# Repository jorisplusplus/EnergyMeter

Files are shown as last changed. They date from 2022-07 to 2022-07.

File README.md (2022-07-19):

PCB and esphome configuration for reading P1 smart meter and RS485 Modbus devices (pv systems)

## Hardware ##
Hardware production files are found in the production folder. These files can be generated with the generate.sh command (requires kikit to be installed).

## ESPHOME ##
In the esphome folder there are 2 configuration files for P1 Meter and Goodwe xs inverter. Note both configurations use the ethernet port

## Housing ##
In the Housing folder the openscad and stl files are present. The pcb should fit pressfit in the housing.

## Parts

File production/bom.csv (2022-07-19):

Comment | Designator | Footprint | LCSC
470uF | C1,C3 | Capacitor_THT:CP_Radial_D8.0mm_P3.50mm | C1590895
DNP | C2,C7,C8,C19,C20 | Capacitor_SMD:C_0603_1608Metric
100nF | C4,C5,C6,C9,C10,C11,C12,C13,C15,C17 | Capacitor_SMD:C_0603_1608Metric | C14663
200pF | C14 | Capacitor_SMD:C_0603_1608Metric | C1600
1uF | C16 | Capacitor_SMD:C_0603_1608Metric | C15849
10nF | C18 | Capacitor_SMD:C_0603_1608Metric | C57112
LED | D1,D2 | LED_SMD:LED_0805_2012Metric | C84256
1N5819 | D3 | Diode_SMD:D_SOD-323 | C191023
10 | FB1 | Resistor_SMD:R_0805_2012Metric | C1017
5V_SELECTOR | J1 | Connector_PinHeader_2.54mm:PinHeader_2x03_P2.54mm_Horizontal
RJ12 | J2,J4 | Connector_RJ:RJ12_Amphenol_54601 | C305981
PS | J3 | Connector_PinHeader_2.54mm:PinHeader_1x03_P2.54mm_Vertical
USB_C_Receptacle_USB2.0 | J5 | Connector_USB:USB_C_Receptacle_HRO_TYPE-C-31-M-12 | C165948
RJ45_Amphenol_RJMG1BD3B8K1ANR | J6 | Connector_RJ:RJ45_Hanrun_HR911105A | C12074
22uH | L1 | Inductor_SMD:L_Taiyo-Yuden_NR-40xx | C83472
S8050 | Q1,Q2 | Package_TO_SOT_SMD:SOT-23 | C2146
470 | R1,R2 | Resistor_SMD:R_0603_1608Metric | C23179
180 | R3 | Resistor_SMD:R_0603_1608Metric | C22828
1K | R4,R5 | Resistor_SMD:R_0603_1608Metric | C21190
DNP | R6 | Resistor_SMD:R_0603_1608Metric
5.1k | R7,R8 | Resistor_SMD:R_0603_1608Metric | C23186
10k | R9,R10 | Resistor_SMD:R_0603_1608Metric | C25804
4K7 | R11,R13,R14,R15,R16 | Resistor_SMD:R_0603_1608Metric | C23162
1K5 | R12 | Resistor_SMD:R_0603_1608Metric | C22843
330 | R17 | Resistor_SMD:R_0603_1608Metric | C23138
270 | R18 | Resistor_SMD:R_0603_1608Metric | C22966
12K1 | R19 | Resistor_SMD:R_0603_1608Metric
49.9 | R20,R21,R22,R23 | Resistor_SMD:R_0603_1608Metric | C23185
0 | R24 | Resistor_SMD:R_0603_1608Metric | C21189
680 | R25,R27 | Resistor_SMD:R_0603_1608Metric | C23228
120 | R26 | Resistor_SMD:R_0603_1608Metric | C22787
1.5K | R28 | Resistor_SMD:R_0603_1608Metric | C22843
10k | R29,R30 | Resistor_SMD:R_0603_1608Metric
ESP32-WROOM-32 | U1 | RF_Module:ESP32-WROOM-32 | C82899
XL1509 | U2 | Package_SO:SOP-8_3.9x4.9mm_P1.27mm | C74192
SN74LVC1T45DCK | U3,U4 | Package_TO_SOT_SMD:SOT-363_SC-70-6 | C133077
SP3485EN | U5 | Package_SO:SOIC-8_3.9x4.9mm_P1.27mm | C8963
CH340C | U6 | Package_SO:SOIC-16_3.9x9.9mm_P1.27mm | C84681
LAN8720A | U7 | Package_DFN_QFN:QFN-24-1EP_4x4mm_P0.5mm_EP2.6x2.6mm | C45223

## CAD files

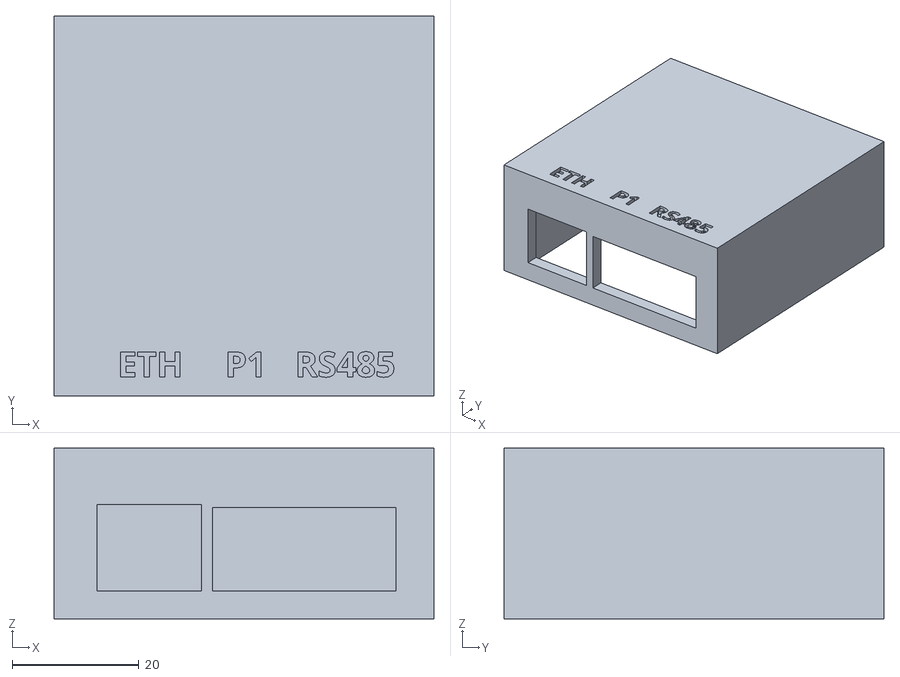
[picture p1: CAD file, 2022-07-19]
Housing/top.stl
60.0 x 60.0 x 27.0

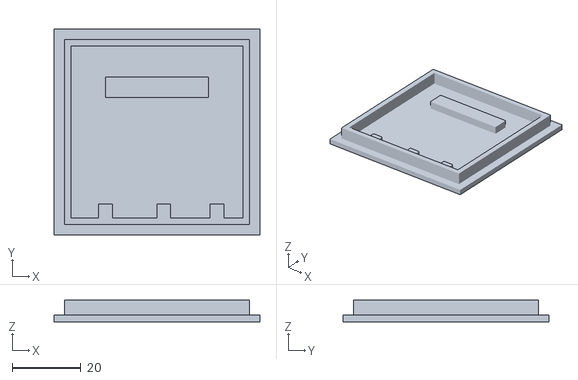
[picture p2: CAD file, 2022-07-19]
Housing/base.stl
60.0 x 60.0 x 6.40

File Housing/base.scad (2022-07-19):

base=2;
clearance=2.8;
pchthick=1.6;
cube([60, 60, base]);
translate([3, 3, 0])
union() {
difference() {
cube([54, 54, base+clearance+pchthick]);
translate([2, 2, 0])
cube([50, 50.1, base+clearance+pchthick]);
}
translate([10, 0, 0])
cube([4, 6, base+clearance]);
translate([27, 0, 0])
cube([4, 6, base+clearance]);
translate([42.5, 0, 0])
cube([4, 6, base+clearance]);
translate([12, 37, 0])
cube([30, 6, base+clearance]);
}

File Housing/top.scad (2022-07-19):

height=27;
clearance=2.8;
pcbthick=1.6;

module textext(strt,h=1) {
    linear_extrude(h) {
    text(strt,4,font="Open Sans:style=Bold");
    }
}

difference() {
union() {
difference() {
cube([60, 60, height]);
translate([2.9, 2.9, 0])
cube([60-2.9*2, 60-2.9*2, height-2]);
translate([6.75, 0, 2.8+1.6])
cube([16.5, 5, 13.7]);
translate([34.5+5-29/2, 0, 2.8+1.6])
cube([29, 5, 13.2]);       
}
translate([0, 30, clearance+pcbthick])
cube([5, 30, height-(clearance+pcbthick)]);

}
translate([0, 31, 0])
cube([3, 27, 8.5+3]);
translate([0, 55-1.3-9.3, clearance+pcbthick-0.1])
cube([10, 9.3, 3.4]);
translate([0, 28+5, clearance+pcbthick-0.1])
cube([10, 9.3, 5.2]);
translate([10, 3, height-0.95])
textext("ETH");
translate([27, 3, height-0.95])
textext("P1");
translate([38, 3, height-0.95])
textext("RS485");
}

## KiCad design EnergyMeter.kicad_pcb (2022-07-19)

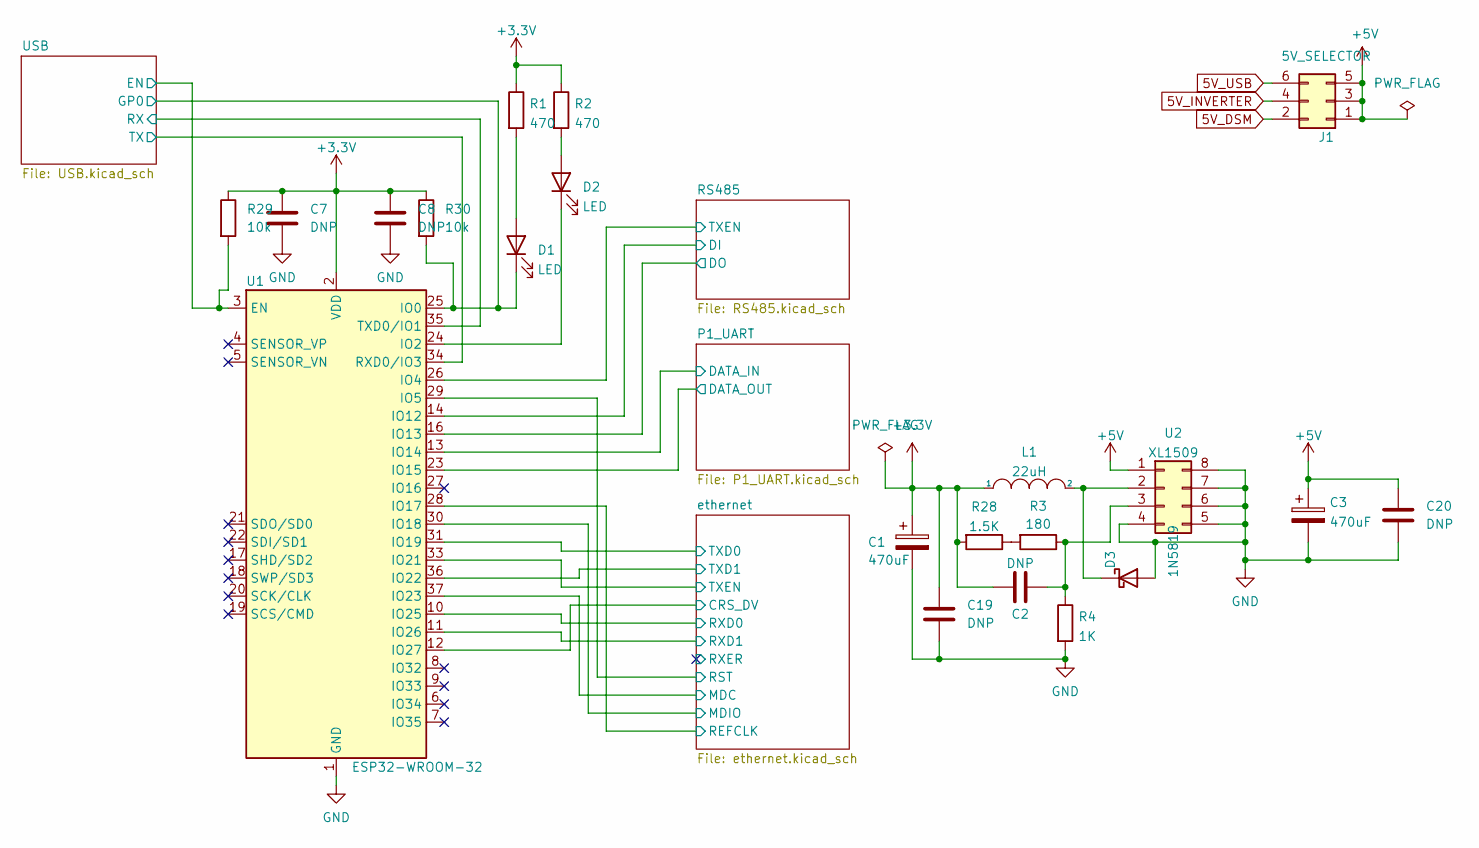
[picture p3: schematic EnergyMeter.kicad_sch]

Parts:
C1, C3: 470uF; CP_Radial_D8.0mm_P3.50mm; LCSC C1590895
C2, C7, C8, C19, C20: DNP; C_0603_1608Metric
D1, D2: LED; LED_0805_2012Metric; LCSC C84256
D3: 1N5819; D_SOD-323; LCSC C191023
J1: 5V_SELECTOR; PinHeader_2x03_P2.54mm_Horizontal
L1: 22uH; L_Taiyo-Yuden_NR-40xx; LCSC C83472
R1, R2: 470; R_0603_1608Metric; LCSC C23179
R3: 180; R_0603_1608Metric; LCSC C22828
R4: 1K; R_0603_1608Metric; LCSC C21190
R28: 1.5K; R_0603_1608Metric; LCSC C22843
R29, R30: 10k; R_0603_1608Metric
U1: ESP32-WROOM-32; LCSC C82899
U2: XL1509; SOP-8_3.9x4.9mm_P1.27mm; LCSC C74192

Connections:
5V_DSM: J1.2; also elsewhere on the board
5V_INVERTER: J1.4; also elsewhere on the board
5V_USB: J1.6; also elsewhere on the board
+3V3: C1.1, C2.1, C7.1, C8.1, C19.1, L1.1, R1.1, R2.1, R28.2, R29.1, R30.1, U1.2 (VDD); also elsewhere on the board
+5V: C3.1, C20.1, J1.1, J1.3, J1.5, U2.1; also elsewhere on the board
/P1_UART/DATA_IN: U1.13 (IO14); also elsewhere on the board
/P1_UART/DATA_OUT: U1.23 (IO15); also elsewhere on the board
/RS485/DI: U1.14 (IO12); also elsewhere on the board
/RS485/DO: U1.16 (IO13); also elsewhere on the board
/RS485/TXEN: U1.26 (IO4); also elsewhere on the board
/USB/EN: R29.2, U1.3 (EN); also elsewhere on the board
/USB/GP0: D1.1 (K), R30.2, U1.25 (IO0); also elsewhere on the board
/USB/RX: U1.35 (TXD0/IO1); also elsewhere on the board
/USB/TX: U1.34 (RXD0/IO3); also elsewhere on the board
/ethernet/CRS_DV: U1.12 (IO27); also elsewhere on the board
/ethernet/MDC: U1.37 (IO23); also elsewhere on the board
/ethernet/MDIO: U1.30 (IO18); also elsewhere on the board
/ethernet/REFCLK: U1.28 (IO17); also elsewhere on the board
/ethernet/RST: U1.29 (IO5); also elsewhere on the board
/ethernet/RXD0: U1.10 (IO25); also elsewhere on the board
/ethernet/RXD1: U1.11 (IO26); also elsewhere on the board
/ethernet/TXD0: U1.31 (IO19); also elsewhere on the board
/ethernet/TXD1: U1.36 (IO22); also elsewhere on the board
/ethernet/TXEN: U1.33 (IO21); also elsewhere on the board
GND: C1.2, C3.2, C7.2, C8.2, C19.2, C20.2, D3.2 (A), R4.2, U1.1 (GND), U1.15 (GND), U1.38 (GND), U1.39 (GND), U2.4, U2.5, U2.6, U2.7, U2.8; also elsewhere on the board
unnamed: C2.2, R3.1, R4.1, U2.3
unnamed: D1.2 (A), R1.2
unnamed: D2.1 (K), U1.24 (IO2)
unnamed: D2.2 (A), R2.2
unnamed: D3.1 (K), L1.2, U2.2
unnamed: R3.2, R28.1

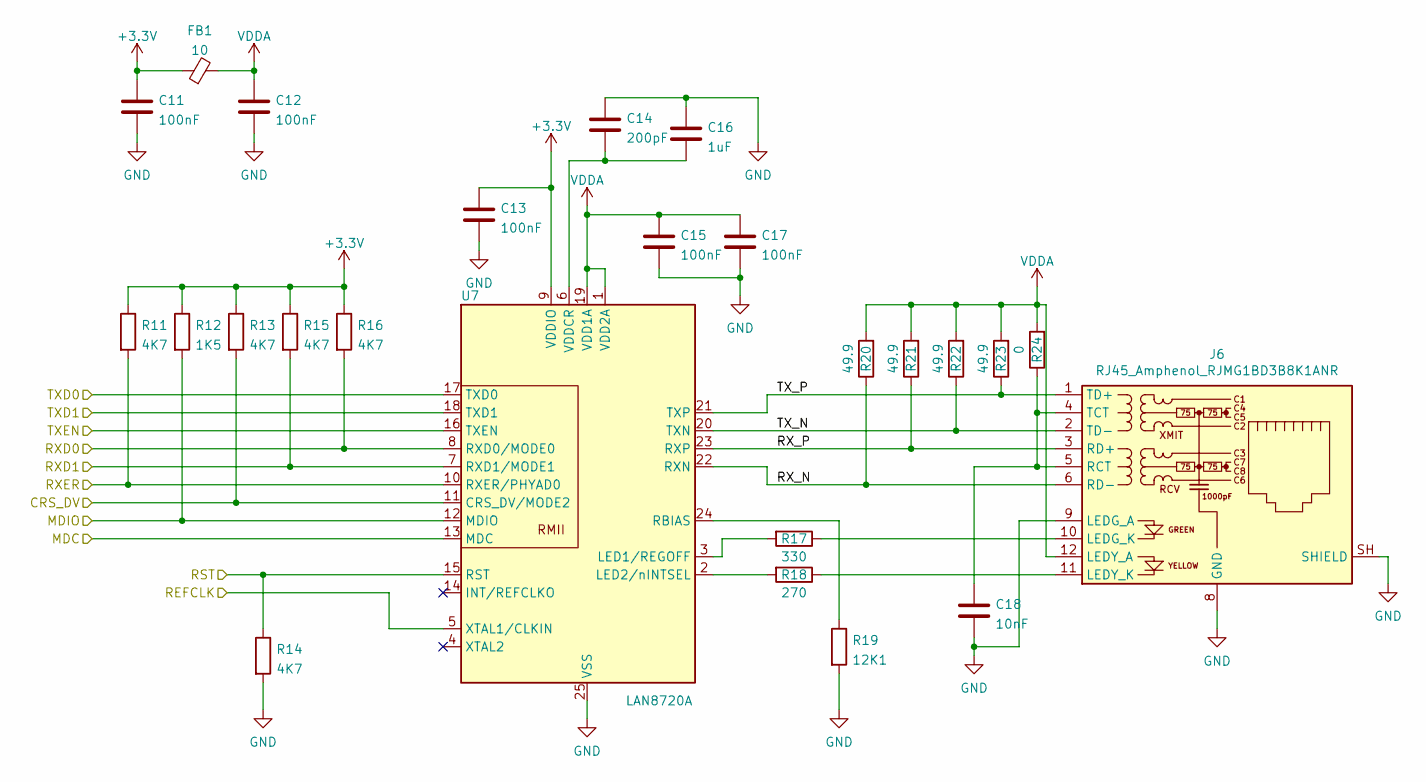
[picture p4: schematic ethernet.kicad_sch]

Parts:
C11, C12, C13, C15, C17: 100nF; C_0603_1608Metric; LCSC C14663
C14: 200pF; C_0603_1608Metric; LCSC C1600
C16: 1uF; C_0603_1608Metric; LCSC C15849
C18: 10nF; C_0603_1608Metric; LCSC C57112
FB1: 10; R_0805_2012Metric; LCSC C1017
J6: RJ45_Amphenol_RJMG1BD3B8K1ANR; RJ45_Hanrun_HR911105A; LCSC C12074
R11, R13, R14, R15, R16: 4K7; R_0603_1608Metric; LCSC C23162
R12: 1K5; R_0603_1608Metric; LCSC C22843
R17: 330; R_0603_1608Metric; LCSC C23138
R18: 270; R_0603_1608Metric; LCSC C22966
R19: 12K1; R_0603_1608Metric
R20, R21, R22, R23: 49.9; R_0603_1608Metric; LCSC C23185
R24: 0; R_0603_1608Metric; LCSC C21189
U7: LAN8720A; QFN-24-1EP_4x4mm_P0.5mm_EP2.6x2.6mm; LCSC C45223

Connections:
+3V3: C11.2, C13.2, FB1.1, R11.1, R12.1, R13.1, R15.1, R16.1, U7.9 (VDDIO); also elsewhere on the board
/ethernet/CRS_DV: R13.2, U7.11 (CRS_DV/MODE2); also elsewhere on the board
/ethernet/MDC: U7.13 (MDC); also elsewhere on the board
/ethernet/MDIO: R12.2, U7.12 (MDIO); also elsewhere on the board
/ethernet/REFCLK: U7.5 (XTAL1/CLKIN); also elsewhere on the board
/ethernet/RST: R14.1, U7.15 (RST); also elsewhere on the board
/ethernet/RXD0: R16.2, U7.8 (RXD0/MODE0); also elsewhere on the board
/ethernet/RXD1: R15.2, U7.7 (RXD1/MODE1); also elsewhere on the board
/ethernet/RXER: R11.2, U7.10 (RXER/PHYAD0)
/ethernet/RX_N: J6.6 (RD-), R20.1, U7.22 (RXN)
/ethernet/RX_P: J6.3 (RD+), R21.1, U7.23 (RXP)
/ethernet/TXD0: U7.17 (TXD0); also elsewhere on the board
/ethernet/TXD1: U7.18 (TXD1); also elsewhere on the board
/ethernet/TXEN: U7.16 (TXEN); also elsewhere on the board
/ethernet/TX_N: J6.2 (TD-), R22.1, U7.20 (TXN)
/ethernet/TX_P: J6.1 (TD+), R23.1, U7.21 (TXP)
GND: C11.1, C12.1, C13.1, C14.1, C15.1, C16.1, C17.1, C18.2, J6.8 (GND), J6.9 (LEDG_A), J6.SH (SHIELD), R14.2, R19.2, U7.25 (VSS); also elsewhere on the board
unnamed: C14.2, C16.2, U7.6 (VDDCR)
unnamed: C18.1, J6.4 (TCT), J6.5 (RCT), R24.1
unnamed: J6.10 (LEDG_K), R17.1
unnamed: J6.11 (LEDY_K), R18.1
unnamed: R17.2, U7.3 (LED1/REGOFF)
unnamed: R18.2, U7.2 (LED2/nINTSEL)
unnamed: R19.1, U7.24 (RBIAS)
VDDA: C12.2, C15.2, C17.2, FB1.2, J6.12 (LEDY_A), R20.2, R21.2, R22.2, R23.2, R24.2, U7.1 (VDD2A), U7.19 (VDD1A)

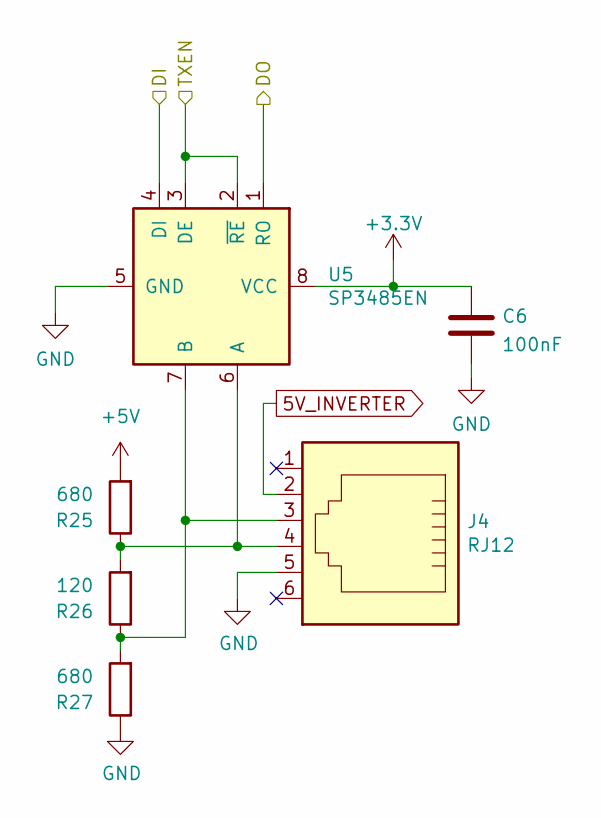
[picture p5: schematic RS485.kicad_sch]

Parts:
C6: 100nF; C_0603_1608Metric; LCSC C14663
J4: RJ12; RJ12_Amphenol_54601; LCSC C305981
R25, R27: 680; R_0603_1608Metric; LCSC C23228
R26: 120; R_0603_1608Metric; LCSC C22787
U5: SP3485EN; SOIC-8_3.9x4.9mm_P1.27mm; LCSC C8963

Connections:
5V_INVERTER: J4.2; also elsewhere on the board
+3V3: C6.1, U5.8 (VCC); also elsewhere on the board
+5V: R25.2; also elsewhere on the board
/RS485/DI: U5.4 (DI); also elsewhere on the board
/RS485/DO: U5.1 (RO); also elsewhere on the board
/RS485/TXEN: U5.2 (~RE), U5.3 (DE); also elsewhere on the board
GND: C6.2, J4.5, R27.1, U5.5 (GND); also elsewhere on the board
unnamed: J4.3, R26.1, R27.2, U5.7 (B)
unnamed: J4.4, R25.1, R26.2, U5.6 (A)

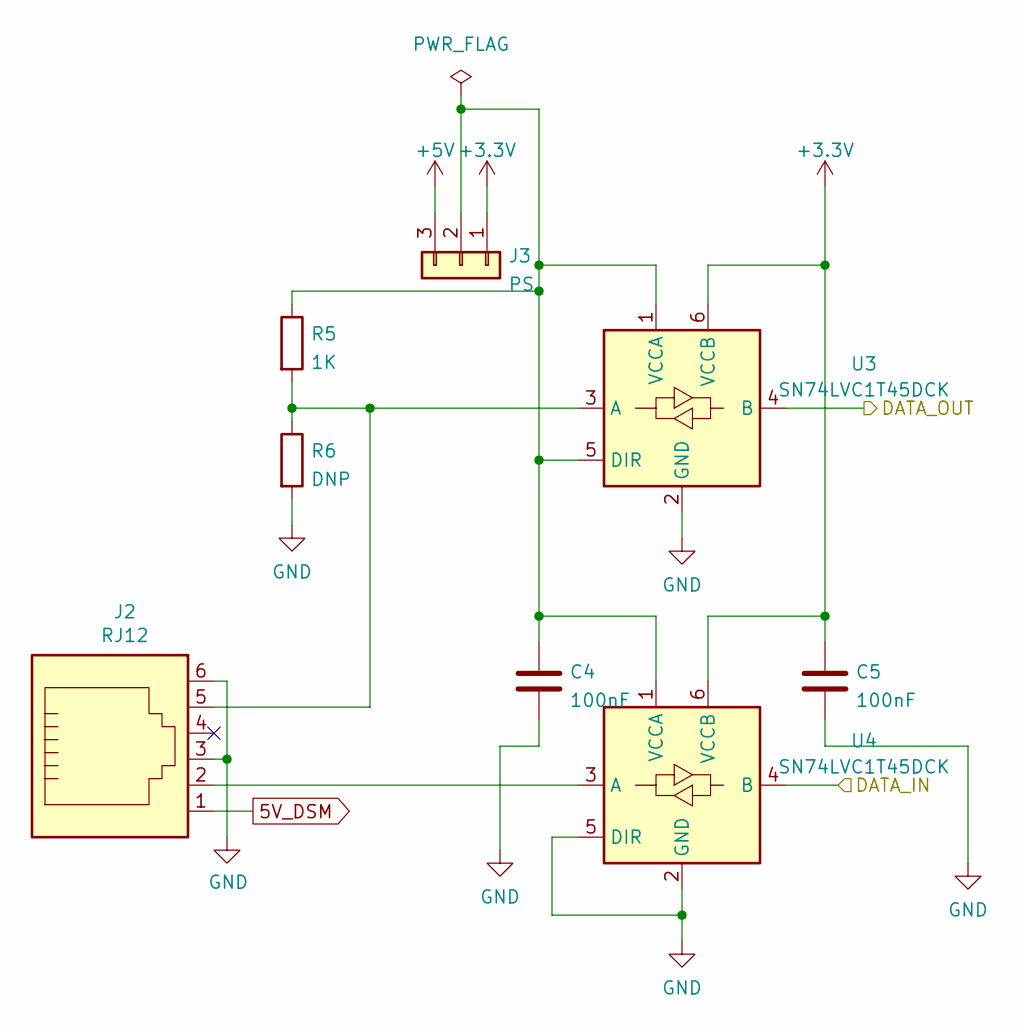
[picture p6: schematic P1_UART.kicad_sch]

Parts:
C4, C5: 100nF; C_0603_1608Metric; LCSC C14663
J2: RJ12; RJ12_Amphenol_54601; LCSC C305981
J3: PS; PinHeader_1x03_P2.54mm_Vertical
R5: 1K; R_0603_1608Metric; LCSC C21190
R6: DNP; R_0603_1608Metric
U3, U4: SN74LVC1T45DCK; SOT-363_SC-70-6; LCSC C133077

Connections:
5V_DSM: J2.1; also elsewhere on the board
+3V3: C5.1, J3.1, U3.6 (VCCB), U4.6 (VCCB); also elsewhere on the board
+5V: J3.3; also elsewhere on the board
/P1_UART/DATA_IN: U4.4 (B); also elsewhere on the board
/P1_UART/DATA_OUT: U3.4 (B); also elsewhere on the board
GND: C4.2, C5.2, J2.3, J2.6, R6.2, U3.2 (GND), U4.2 (GND), U4.5 (DIR); also elsewhere on the board
unnamed: C4.1, J3.2, R5.1, U3.1 (VCCA), U3.5 (DIR), U4.1 (VCCA)
unnamed: J2.2, U4.3 (A)
unnamed: J2.5, R5.2, R6.1, U3.3 (A)

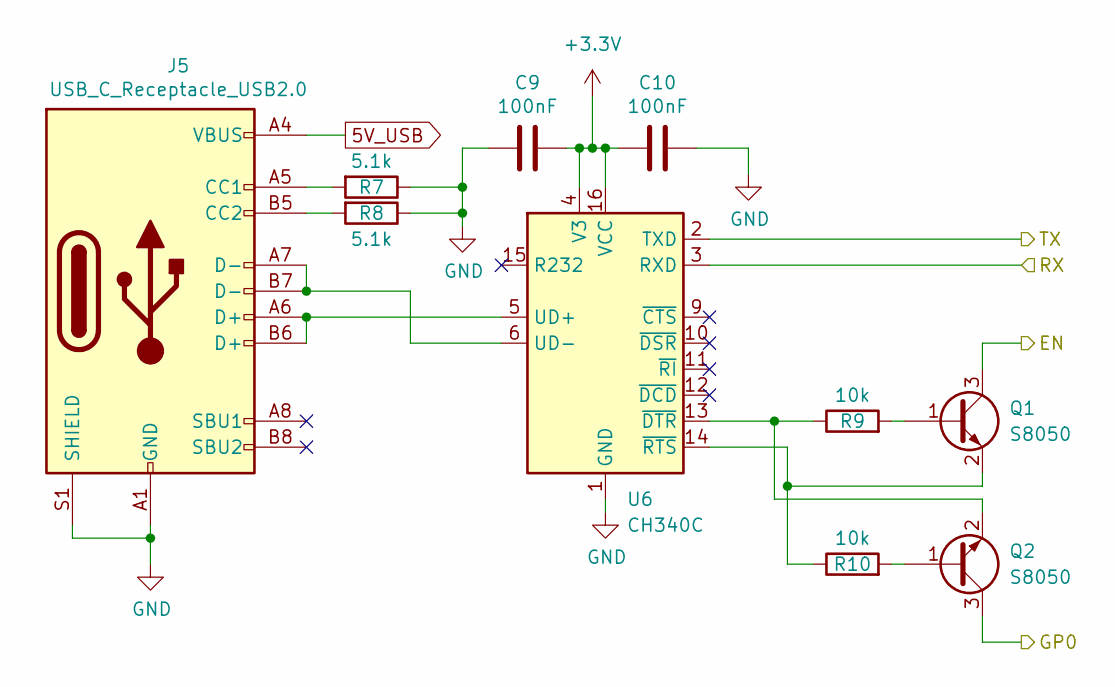
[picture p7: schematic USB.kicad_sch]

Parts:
C9, C10: 100nF; C_0603_1608Metric; LCSC C14663
J5: USB_C_Receptacle_USB2.0; USB_C_Receptacle_HRO_TYPE-C-31-M-12; LCSC C165948
Q1, Q2: S8050; SOT-23; LCSC C2146
R7, R8: 5.1k; R_0603_1608Metric; LCSC C23186
R9, R10: 10k; R_0603_1608Metric; LCSC C25804
U6: CH340C; SOIC-16_3.9x9.9mm_P1.27mm; LCSC C84681

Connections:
5V_USB: J5.A4 (VBUS), J5.A9 (VBUS), J5.B4 (VBUS), J5.B9 (VBUS); also elsewhere on the board
+3V3: C9.1, C10.2, U6.4 (V3), U6.16 (VCC); also elsewhere on the board
/USB/EN: Q1.3 (C); also elsewhere on the board
/USB/GP0: Q2.3 (C); also elsewhere on the board
/USB/RX: U6.3 (RXD); also elsewhere on the board
/USB/TX: U6.2 (TXD); also elsewhere on the board
GND: C9.2, C10.1, J5.A1 (GND), J5.A12 (GND), J5.B1 (GND), J5.B12 (GND), J5.S1 (SHIELD), R7.1, R8.1, U6.1 (GND); also elsewhere on the board
unnamed: J5.A5 (CC1), R7.2
unnamed: J5.A6 (D+), J5.B6 (D+), U6.5 (UD+)
unnamed: J5.A7 (D-), J5.B7 (D-), U6.6 (UD-)
unnamed: J5.B5 (CC2), R8.2
unnamed: Q1.1 (B), R9.2
unnamed: Q1.2 (E), R10.1, U6.14 (~RTS)
unnamed: Q2.1 (B), R10.2
unnamed: Q2.2 (E), R9.1, U6.13 (~DTR)

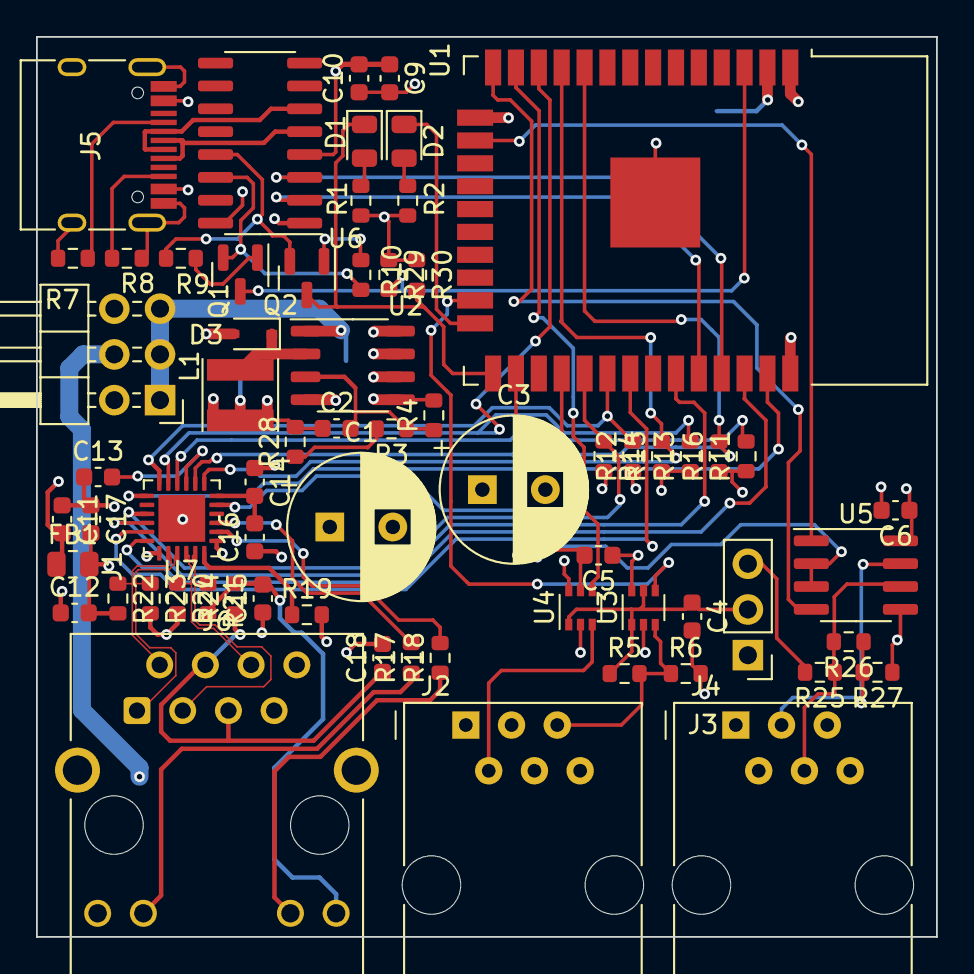
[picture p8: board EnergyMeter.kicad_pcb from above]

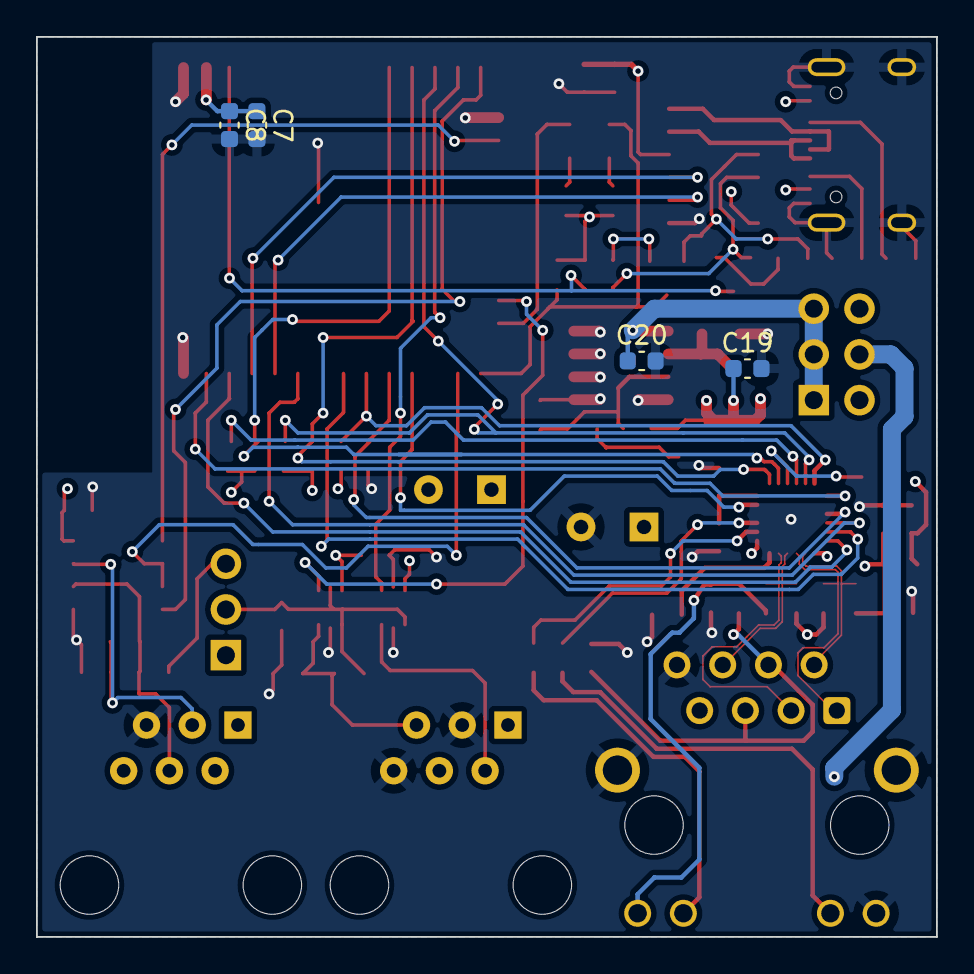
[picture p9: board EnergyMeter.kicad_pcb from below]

Board: 4 copper layers, 50.0 x 50.0 mm, 70 parts (4 on the bottom side), 57 nets.

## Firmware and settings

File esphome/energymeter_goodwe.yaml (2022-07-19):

esphome:
  name: energymeter
  platform: ESP32
  board: esp32dev

logger:
  level: VERBOSE

ethernet:
  type: LAN8720
  mdc_pin: GPIO23
  mdio_pin: GPIO18
  clk_mode: GPIO17_OUT
  phy_addr: 1
  power_pin: GPIO5

status_led:
  pin: GPIO0

time:
  - platform: sntp
    id: my_time

api:

ota:

web_server:
  port: 80

uart:
  - id: mod_bus
    tx_pin: GPIO12
    rx_pin: GPIO13
    baud_rate: 9600
    stop_bits: 1
  - id: dsmr_bus
    baud_rate: 115200
    rx_pin: 
      number: GPIO15
      inverted: true
      mode:
        input: true

modbus:
  flow_control_pin: GPIO4
  id: modbus1
  uart_id: mod_bus

modbus_controller:
  - id: epever
    ## the Modbus device addr
    address: 247
    modbus_id: modbus1
    setup_priority: -10

sensor:
  - platform: modbus_controller
    modbus_controller_id: epever
    name: "Power"
    id: inverter_power
    state_class: measurement
    device_class: power
    icon: mdi:flash-outline
    register_type: holding
    address: 0x0233
    unit_of_measurement: "W"
    value_type: U_WORD
  - platform: modbus_controller
    modbus_controller_id: epever
    name: "Energy"
    id: inverter_energy
    state_class: total_increasing
    device_class: energy
    register_type: holding
    address: 0x0222
    unit_of_measurement: "kWh"
    value_type: U_DWORD
    accuracy_decimals: 1
    filters:
      - multiply: 0.1
  - platform: modbus_controller
    modbus_controller_id: epever
    name: "Vac"
    id: inverter_vac
    register_type: holding
    address: 0x0304
    unit_of_measurement: "V"
    value_type: U_WORD
    accuracy_decimals: 1
    filters:
      - multiply: 0.1
  - platform: modbus_controller
    modbus_controller_id: epever
    name: "Iac"
    id: inverter_iac
    register_type: holding
    address: 0x0307
    unit_of_measurement: "A"
    value_type: U_WORD
    accuracy_decimals: 1
    filters:
      - multiply: 0.1
  - platform: modbus_controller
    modbus_controller_id: epever
    name: "Vpv"
    id: inverter_vpv
    register_type: holding
    address: 0x0300
    unit_of_measurement: "V"
    value_type: U_WORD
    accuracy_decimals: 1
    filters:
      - multiply: 0.1
  - platform: modbus_controller
    modbus_controller_id: epever
    name: "Ipv"
    id: inverter_ipv
    register_type: holding
    address: 0x0302
    unit_of_measurement: "A"
    value_type: U_WORD
    accuracy_decimals: 1
    filters:
      - multiply: 0.1

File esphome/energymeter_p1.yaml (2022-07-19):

esphome:
  name: energymeter_p1
  platform: ESP32
  board: esp32dev
  on_boot:
    priority: -100
    then:
     - output.turn_on: gpio_dsmr
logger:
  level: VERBOSE

ethernet:
  type: LAN8720
  mdc_pin: GPIO23
  mdio_pin: GPIO18
  clk_mode: GPIO17_OUT
  phy_addr: 1
  power_pin: GPIO5

output:
 - platform: gpio
   pin: GPIO14
   id: gpio_dsmr

status_led:
  pin: GPIO0

time:
  - platform: sntp
    id: my_time

api:

ota:

web_server:
  port: 80

uart:
  - id: dsmr_bus
    baud_rate: 115200
    rx_buffer_size: 1700
    rx_pin: 
      number: GPIO15
      inverted: true
      mode:
        input: true

dsmr:
  id: dsmr_instance
  max_telegram_length: 1700

sensor:
  - platform: dsmr
    energy_delivered_tariff1:
      name: "Energy Consumed Tariff 1"
    energy_delivered_tariff2:
      name: "Energy Consumed Tariff 2"
    energy_returned_tariff1:
      name: "Energy Produced Tariff 1"
    energy_returned_tariff2:
      name: "Energy Produced Tariff 2"
    power_delivered:
      name: "Power Consumed"
      accuracy_decimals: 3
    power_returned:
      name: "Power Produced"
      accuracy_decimals: 3
    electricity_failures:
      name: "Electricity Failures"
      icon: mdi:alert
    electricity_long_failures:
      name: "Long Electricity Failures"
      icon: mdi:alert
    voltage_l1:
      name: "Voltage Phase 1"
    voltage_l2:
      name: "Voltage Phase 2"
    voltage_l3:
      name: "Voltage Phase 3"
    current_l1:
      name: "Current Phase 1"
    current_l2:
      name: "Current Phase 2"
    current_l3:
      name: "Current Phase 3"
    power_delivered_l1:
      name: "Power Consumed Phase 1"
      accuracy_decimals: 3
    power_delivered_l2:
      name: "Power Consumed Phase 2"
      accuracy_decimals: 3
    power_delivered_l3:
      name: "Power Consumed Phase 3"
      accuracy_decimals: 3
    power_returned_l1:
      name: "Power Produced Phase 1"
      accuracy_decimals: 3
    power_returned_l2:
      name: "Power Produced Phase 2"
      accuracy_decimals: 3
    power_returned_l3:
      name: "Power Produced Phase 3"
      accuracy_decimals: 3
    gas_delivered:
      name: "Gas Consumed"
  - platform: uptime
    name: "Uptime"

text_sensor:
  - platform: dsmr
    identification:
      name: "DSMR Identification"
    p1_version:
      name: "DSMR Version"
  - platform: version
    name: "ESPHome Version"
    hide_timestamp: true
